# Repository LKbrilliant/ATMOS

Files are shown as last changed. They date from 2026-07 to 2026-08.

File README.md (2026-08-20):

# ATMOS
ATMOS is an embedded, standalone weather forecasting display based on ESP32-S3.

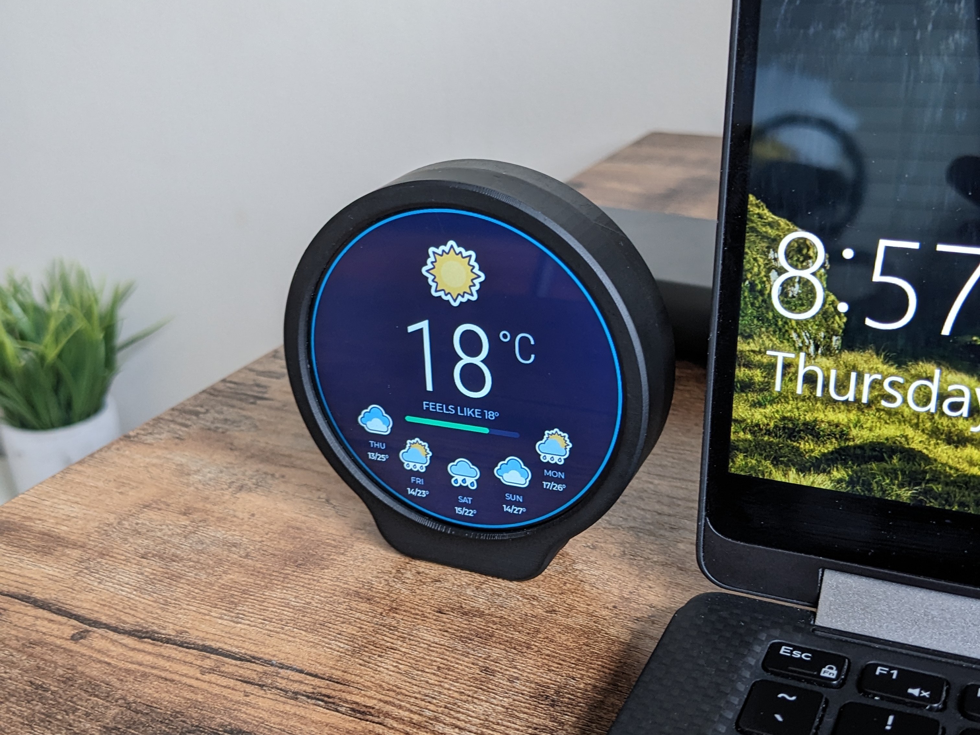
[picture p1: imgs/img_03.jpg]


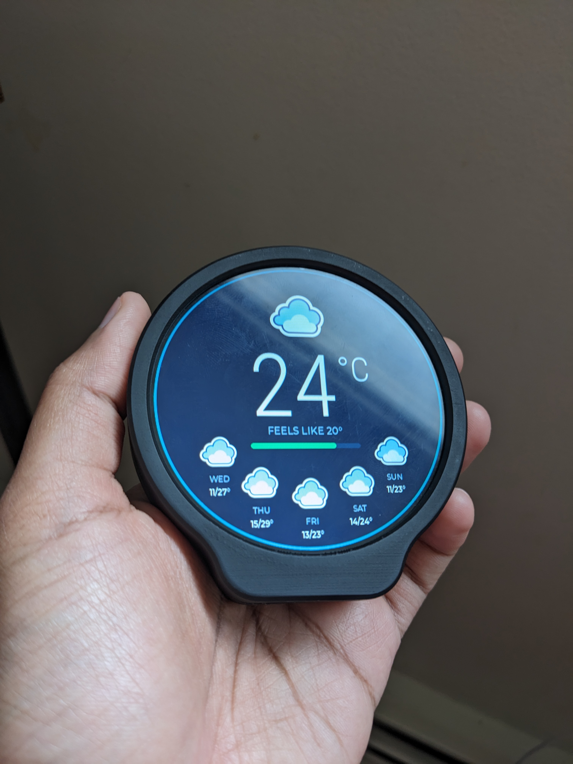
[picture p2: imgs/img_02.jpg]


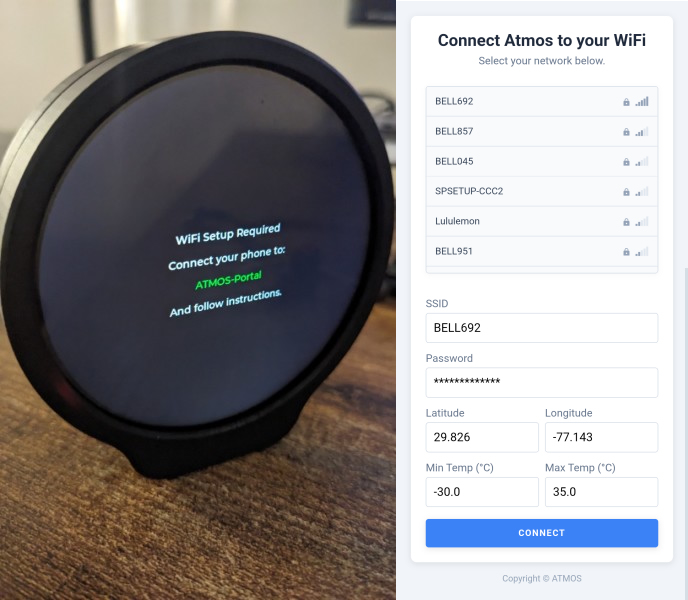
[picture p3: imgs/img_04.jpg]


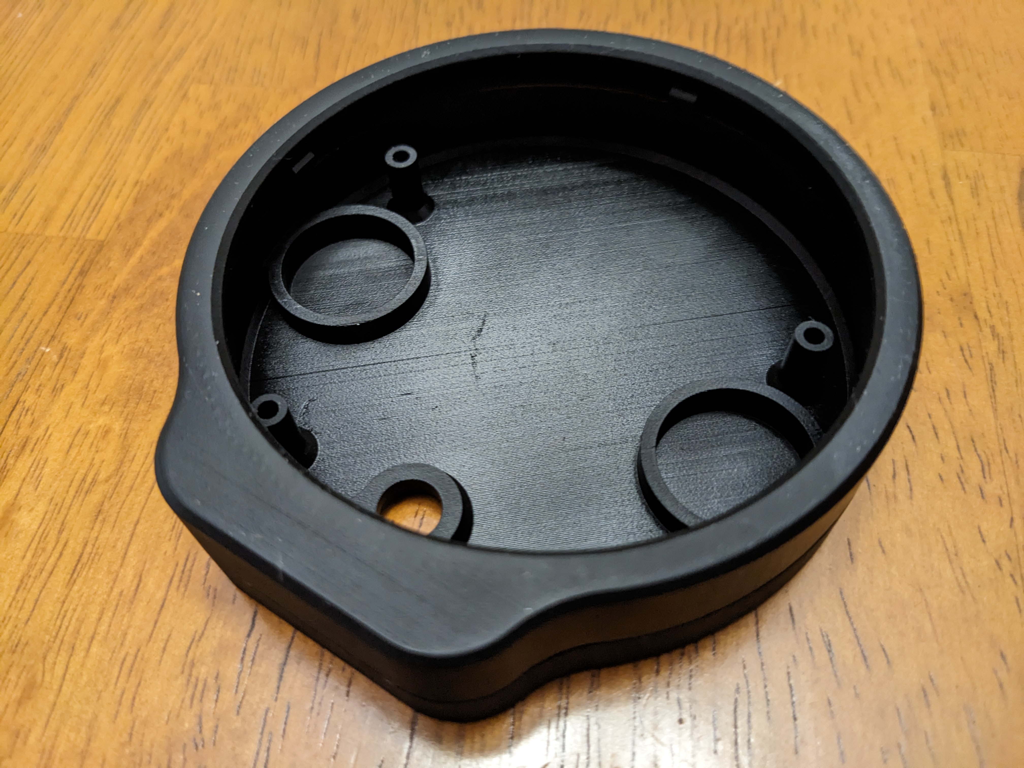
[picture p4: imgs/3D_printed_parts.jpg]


## Features

* **Automatic Captive Portal:** If no saved Wi-Fi network is found on boot, the device automatically broadcasts a setup Access Point and captive portal.
* **One-Time Configuration:** Easily set up Wi-Fi credentials, GPS coordinates, and custom/local yearly min-max temperature thresholds through the browser interface—stored permanently in NVS memory.
* **Hardware Factory Reset:** Press and hold the onboard **BOOT** button for >3 seconds to erase saved network credentials and location data.
* **Weather Data:** Integrates with the [Open-Meteo API](https://open-meteo.com/) to fetch current and forecast metrics (weather, current temperature, "feels like" temperature, and daily min/max temperatures).
* **Comfort Bar:** Generates a color gradient bar based on your custom temperature bounds:
  * **Min Temp** $\rightarrow$ Cold (Purple)
  * **21 °C** $\rightarrow$ Ideal Comfort (Green)
  * **Max Temp** $\rightarrow$ Hot (Red)
* **Tap/raise to wake up:** Gently tap or bump the unit to wake the display and boost brightness back to 100%

## Known issues
- Color inversion and upward shift of the display at the first UI draw (right after setting the credentials). Quick reset or power on/off will resolve the issue. This only occur at the initial setup.

### Hardware
- Display: Waveshare ESP32-S3 2.8" non-touch
- 1GB micro SD card (FAT32) with the weather icons (.bin formatted) in its root directory.
- 3D printed enclosure
- 2000mAh lipo battery
- USB type C female connector
- Latching switch
- 4x M2-15mm mounting screws

### External libraries
- WiFi provisioner: https://github.com/MichMich/esp-idf-wifi-provisioner

### Custom fonts
- Used LVGL online font converter:  https://lvgl.io/tools/fontconverter
    - Bpp:4 bit-per-pixel
    - output format: C file
- Place the C file in the main.c directory
- in the font C file comment out "// .static_bitmap = 0" line. This gave me an error when uncommented.
- Add the font file name to "SRCS" list in CMakeLists.txt

### Weather icons
- Sticker style weather icons: https://icons8.com/icons/set/weather--style-stickers

### Image transform scripts
- src/scripts/resizer.py: Used to batch resize images in a given directory
- src/scripts/img_to_bin_lvgl_v8: Used to convert regular image files in to .bin files to load on display with minimum RAM usage.

# Notes

### Build instructions using ESP-IDF via VScode
- Started from the the manufacturer's (waveshare) demo files which uses LVGL v8
- Install ESP IDF for vs code - IDF version: v5.5.2
- Connect the USB cable to UART or USB port of the device
- Select flash method: UART or USB-JTAG based on the connected port
- Select the USB port using the detect button on VScode (this option is enabled via ESP IDF)
- Select the target: ESP32-S3 (via built in USB-JTAG)
- Do a 'Full clean'
- Then 'Build'

### Changes to the vscode ESP-IDF environment
- Enable fonts
    - lv_font_montserrat_12
    - lv_font_montserrat_16
    - lv_font_montserrat_48
- Enable 'File system on top of posix API' needed for custom file system wrapper
    - Drive letter = '83' for letter S
    - working directory = /sdcard
- FAT Filesystem support -> Long file name support = 'long file name buffer in heap'
    - Note: Maybe this is why I had to implement a custom file wrapper. By default files were not opening may be due to file name length restriction.
    - Note: Could have put the images in the ESP32 instead of the SD card.

### Disclaimer
- Most of the code in this repository was generated with the assistance of AI. While reasonable effort has been made to review and test the generated code, it has not been formally audited. Use this software at your own risk, and verify its correctness and security before deploying it in production.

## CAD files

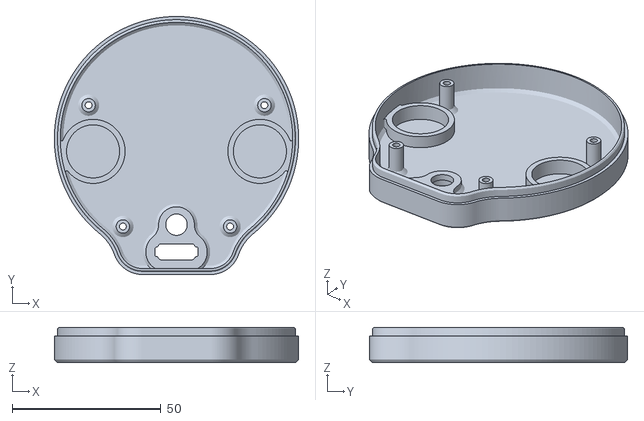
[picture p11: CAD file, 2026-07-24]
CAD/enclosure-case_back.stl
82.0 x 86.6 x 11.8

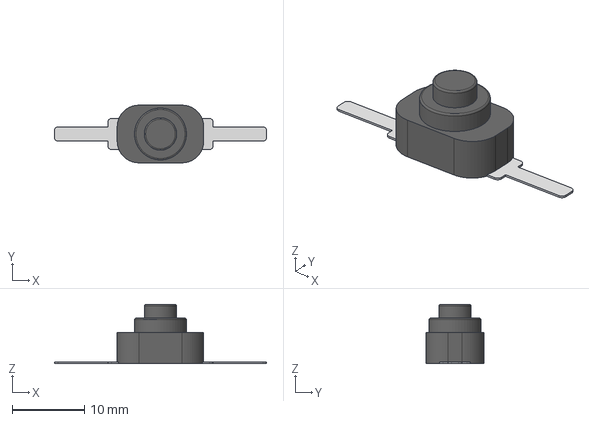
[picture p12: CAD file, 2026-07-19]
CAD/components/Power button.step
29.4 x 8.00 x 8.20 mm

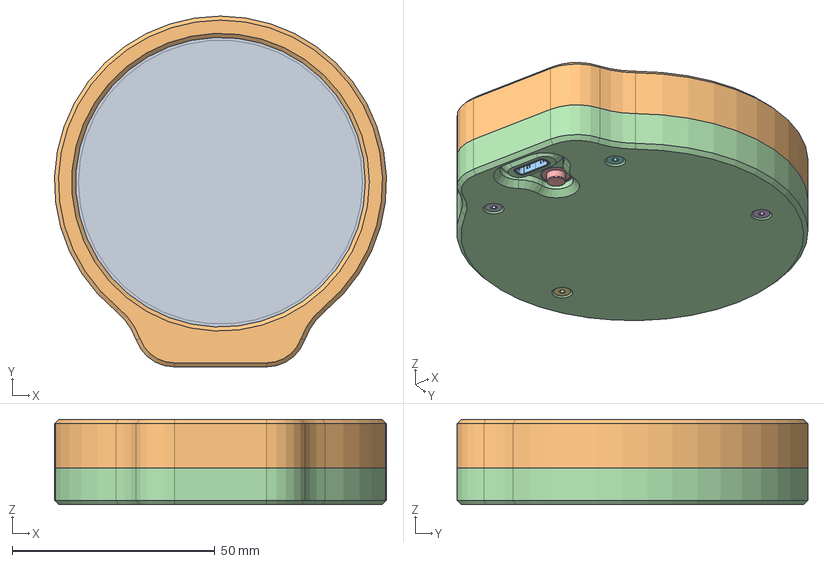
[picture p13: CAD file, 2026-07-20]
CAD/enclosure.FCStd
82.0 x 86.6 x 21.0 mm
Display
case_front
battery_103450
case_back
USB Connector Type C female v1
USB Connector Type C female v001
USB Connector Type C female v002
USB Connector Type C female v003
USB Connector Type C female v004
USB Connector Type C female v005
USB Connector Type C female v006
USB Connector Type C female v007
USB Connector Type C female v008
USB Connector Type C female v009
USB Connector Type C female v010
USB Connector Type C female v011
USB Connector Type C female v012
USB Connector Type C female v013
USB Connector Type C female v014
USB Connector Type C female v015
USB Connector Type C female v016
USB Connector Type C female v017
USB Connector Type C female v018
USB Connector Type C female v019
USB Connector Type C female v020
USB Connector Type C female v021
USB Connector Type C female v022
USB Connector Type C female v023
USB Connector Type C female v024
USB Connector Type C female v025
USB Connector Type C female v026
USB Connector Type C female v027
USB Connector Type C female v028
USB Connector Type C female v029
USB Connector Type C female v030
switch
screw_01
screw_02
screw_03
screw_04

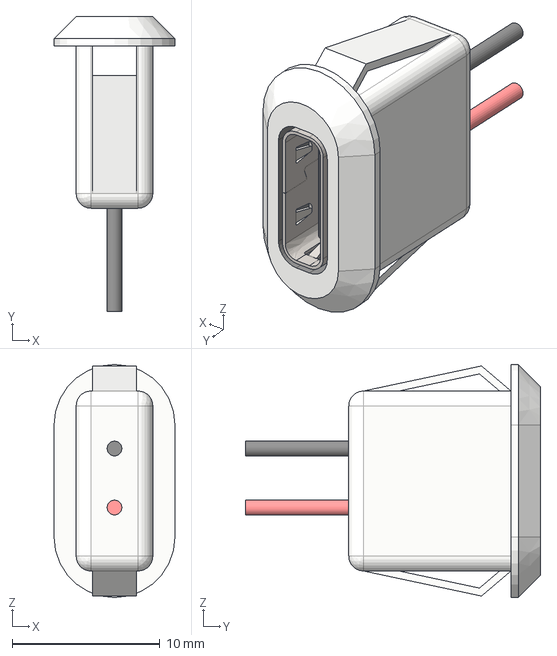
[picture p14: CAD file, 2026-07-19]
CAD/components/type c jack connector.step
8.20 x 20.0 x 15.8 mm
USB Connector Type C female

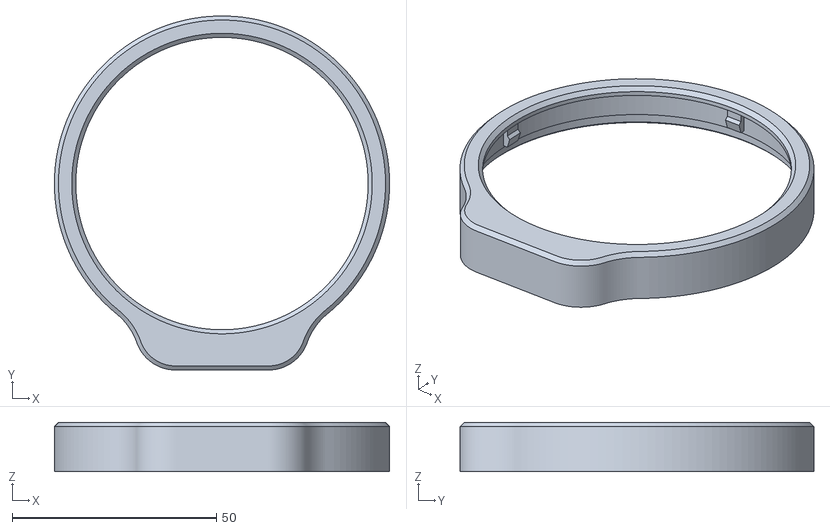
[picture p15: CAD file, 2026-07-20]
CAD/enclosure-case_front.stl
82.0 x 86.6 x 12.0

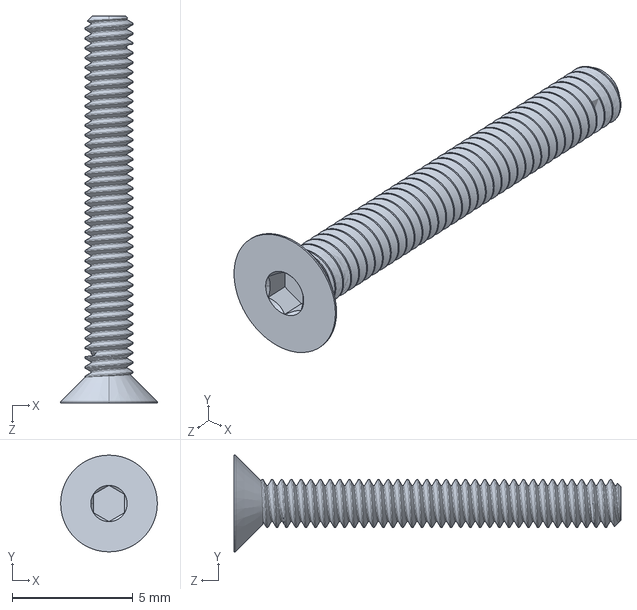
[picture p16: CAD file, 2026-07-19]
CAD/components/92125A059_18-8 Stainless Steel Hex-Drive Flat Head Screw.STEP
4.00 x 4.00 x 16.0 mm

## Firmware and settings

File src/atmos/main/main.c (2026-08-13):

#include <stdio.h>
#include <math.h>
#include <time.h>

#include "sdkconfig.h"
#include "freertos/FreeRTOS.h"
#include "freertos/task.h"
#include "freertos/semphr.h"
#include "driver/ledc.h"
#include "driver/gpio.h"
#include "esp_log.h"
#include "esp_http_client.h"
#include "esp_wifi.h"
#include "esp_sleep.h"
#include "esp_timer.h"
#include "cJSON.h"

#include "QMI8658.h"
#include "ST7701S.h"
#include "TCA9554PWR.h"
#include "SD_MMC.h"
#include "LVGL_Driver.h"
#include "LVGL_Example.h"
#include "BAT_Driver.h"
#include "wifi_provisioner.h"
#include "nvs_flash.h"

/* --- LOG TAG --- */
static const char *TAG = "ATMOS_MAIN";

/* --- FONTS --- */
LV_FONT_DECLARE(roboto_condensed_light_150)
LV_FONT_DECLARE(roboto_condensed_light_60)

/* --- CONFIGURATION & CONSTANTS --- */
#define UPDATE_INTERVAL_MIN    15
#define MAX_HTTP_RECV_BUFFER   4096

#define COLOR_APP_BACKGROUND   0x0F172A // Dark Blue
#define COLOR_OUTER_RING       0x06B6D4 // Cyan / Bright Blue

#define RESET_BUTTON_GPIO      GPIO_NUM_0
#define HOLD_TIME_MS           3000

#define BACKLIGHT_PIN          GPIO_NUM_6
#define BACKLIGHT_SPEED_MODE   LEDC_LOW_SPEED_MODE
#define BACKLIGHT_CHANNEL      LEDC_CHANNEL_0
#define BACKLIGHT_TIMER        LEDC_TIMER_0
#define BACKLIGHT_DUTY_RES     LEDC_TIMER_10_BIT

#define BRIGHTNESS_DIM_TIMEOUT_MS   20000
#define BRIGHTNESS_HIGH             100   // Full brightness percentage
#define BRIGHTNESS_LOW              10    // Dimmed brightness percentage

#define TAP_THRESHOLD_G             0.07f  // Acceleration magnitude change threshold in g (best=0.07f)
#define TAP_DEBOUNCE_MS             300   // Minimum time between tap detections

static esp_timer_handle_t dim_timer = NULL;
static uint32_t last_tap_time_ms = 0;

/* --- FALLBACK VALUES --- */
static float g_temp_low_end = -30.0f;
static float g_temp_high_end = 35.0f;
static char g_latitude[16]   = "49.826";
static char g_longitude[16]  = "-97.143";

static SemaphoreHandle_t lvgl_mux = NULL;
static lv_obj_t *wifi_status_label = NULL;
static lv_obj_t *wifi_screen = NULL;
static lv_fs_drv_t my_sd_drv;

/* --- PERSISTENT LVGL UI HANDLES --- */
static lv_obj_t * main_icon_img   = NULL;
static lv_obj_t * temp_num_label  = NULL;
static lv_obj_t * temp_unit_lbl   = NULL;
static lv_obj_t * feels_like_lbl  = NULL;
static lv_obj_t * range_bar_obj   = NULL;
static lv_obj_t * sub_icons[5]    = {NULL};
static lv_obj_t * day_labels[5]   = {NULL};
static lv_obj_t * min_max_lbls[5] = {NULL};

/* --- DATA STRUCTURES --- */
typedef struct {
    float temp;
    float feels_like;
    int weather_code;
    int is_day;
} current_weather_t;

typedef struct {
    char date[8][16];
    float temp_max[8];
    float temp_min[8];
    int weather_code[8];
    float moon_phase[8];
} forecast_weather_t;

static current_weather_t current_weather;
static forecast_weather_t forecast_weather;

/* --- LVGL MUTEX LOCK HELPER FUNCTIONS --- */
void lvgl_lock(void) 
{
    if (lvgl_mux != NULL) {
        xSemaphoreTake(lvgl_mux, portMAX_DELAY);
    }
}

void lvgl_unlock(void) 
{
    if (lvgl_mux != NULL) {
        xSemaphoreGive(lvgl_mux);
    }
}

/* --- HARDWARE & BACKLIGHT HANDLERS --- */
void init_backlight_pwm(void) 
{
    ledc_timer_config_t ledc_timer = {
        .speed_mode       = BACKLIGHT_SPEED_MODE,
        .timer_num        = BACKLIGHT_TIMER,
        .duty_resolution  = BACKLIGHT_DUTY_RES,
        .freq_hz          = 5000,
        .clk_cfg          = LEDC_AUTO_CLK
    };
    ledc_timer_config(&ledc_timer);

    ledc_channel_config_t ledc_channel = {
        .speed_mode     = BACKLIGHT_SPEED_MODE,
        .channel        = BACKLIGHT_CHANNEL,
        .timer_sel      = BACKLIGHT_TIMER,
        .intr_type      = LEDC_INTR_DISABLE,
        .gpio_num       = BACKLIGHT_PIN,
        .duty           = 1023,
        .hpoint         = 0
    };
    ledc_channel_config(&ledc_channel);
}

void set_backlight_brightness(uint8_t brightness_percent) 
{
    if (brightness_percent > 100) brightness_percent = 100;
    uint32_t duty = (uint32_t)((brightness_percent / 100.0f) * 1023.0f);

    ledc_set_duty(BACKLIGHT_SPEED_MODE, BACKLIGHT_CHANNEL, duty);
    ledc_update_duty(BACKLIGHT_SPEED_MODE, BACKLIGHT_CHANNEL);
}

static void dim_timer_callback(void* arg)
{
    set_backlight_brightness(BRIGHTNESS_LOW);
}

void reset_backlight_dim_timer(void)
{
    if (dim_timer == NULL) {
        const esp_timer_create_args_t timer_args = {
            .callback = &dim_timer_callback,
            .name = "backlight_dim_timer"
        };
        esp_timer_create(&timer_args, &dim_timer);
    } else {
        esp_timer_stop(dim_timer);
    }

    esp_timer_start_once(dim_timer, BRIGHTNESS_DIM_TIMEOUT_MS * 1000ULL);
}

void wakeup_display_and_stat_dim_timer(void)
{
    set_backlight_brightness(BRIGHTNESS_HIGH);
    reset_backlight_dim_timer();
}

void check_tap_event(void)
{
    // Calculate total acceleration magnitude vector: sqrt(x^2 + y^2 + z^2)
    float magnitude = sqrtf((Accel.x * Accel.x) + (Accel.y * Accel.y) + (Accel.z * Accel.z));

    // Under normal gravity at rest, magnitude ~1.0g.
    float delta_g = fabsf(magnitude - 1.0f);

    uint32_t current_time_ms = (uint32_t)(esp_timer_get_time() / 1000ULL);

    if (delta_g > TAP_THRESHOLD_G && (current_time_ms - last_tap_time_ms) > TAP_DEBOUNCE_MS) {
        last_tap_time_ms = current_time_ms;
        
        wakeup_display_and_stat_dim_timer();
    }
}

void reset_wifi_and_restart(void)
{
    ESP_LOGW("RESET", "Erasing Wi-Fi credentials via wifi_provisioner...");
    esp_err_t err = wifi_prov_erase_credentials();
    if (err == ESP_OK) {
        ESP_LOGI("RESET", "Wi-Fi credentials erased successfully.");
    } else {
        ESP_LOGE("RESET", "Failed to erase credentials: %s", esp_err_to_name(err));
    }

    vTaskDelay(pdMS_TO_TICKS(500));
    esp_sleep_enable_timer_wakeup(100 * 1000);
    esp_deep_sleep_start();
}

static void reset_button_task(void *pvParameters)
{
    gpio_config_t io_conf = {
        .pin_bit_mask = (1ULL << RESET_BUTTON_GPIO),
        .mode = GPIO_MODE_INPUT,
        .pull_up_en = GPIO_PULLUP_ENABLE,
        .pull_down_en = GPIO_PULLDOWN_DISABLE,
        .intr_type = GPIO_INTR_DISABLE,
    };
    gpio_config(&io_conf);

    uint32_t press_duration = 0;

    while (1) {
        if (gpio_get_level(RESET_BUTTON_GPIO) == 0) {
            press_duration += 100;
            if (press_duration >= HOLD_TIME_MS) {
                ESP_LOGI("RESET", "Reset button hold detected!");
                reset_wifi_and_restart();
            }
        } else {
            press_duration = 0;
        }
        vTaskDelay(pdMS_TO_TICKS(100));
    }
}

void reset_button_init(void)
{
    xTaskCreate(reset_button_task, "reset_button_task", 4096, NULL, 10, NULL);
}

/* --- LVGL CUSTOM SD CARD VFS CALLBACKS --- */
static void * fs_open_cb(struct _lv_fs_drv_t * drv, const char * path, lv_fs_mode_t mode) 
{
    const char * flags = "";
    if(mode == LV_FS_MODE_WR) flags = "wb";
    else if(mode == LV_FS_MODE_RD) flags = "rb";
    else if(mode == (LV_FS_MODE_WR | LV_FS_MODE_RD)) flags = "r+b";

    char full_path[128];
    if (path[0] == '/') {
        snprintf(full_path, sizeof(full_path), "/sdcard%s", path);
    } else {
        snprintf(full_path, sizeof(full_path), "/sdcard/%s", path);
    }

    FILE *f = fopen(full_path, flags);
    if (f == NULL) {
        printf("[LVGL FS ERROR] Failed to open: %s\n", full_path);
    }
    return (void *)f;
}

static lv_fs_res_t fs_close_cb(struct _lv_fs_drv_t * drv, void * file_p) 
{
    if(!file_p) return LV_FS_RES_INV_PARAM;
    fclose((FILE *)file_p);
    return LV_FS_RES_OK;
}

static lv_fs_res_t fs_read_cb(struct _lv_fs_drv_t * drv, void * file_p, void * buf, uint32_t btr, uint32_t * br) 
{
    if(!file_p || !buf) return LV_FS_RES_INV_PARAM;
    *br = fread(buf, 1, btr, (FILE *)file_p);
    return LV_FS_RES_OK;
}

static lv_fs_res_t fs_seek_cb(struct _lv_fs_drv_t * drv, void * file_p, uint32_t pos, lv_fs_whence_t whence) 
{
    if(!file_p) return LV_FS_RES_INV_PARAM;
    int w = SEEK_SET;
    if(whence == LV_FS_SEEK_CUR) w = SEEK_CUR;
    else if(whence == LV_FS_SEEK_END) w = SEEK_END;
    
    fseek((FILE *)file_p, pos, w);
    return LV_FS_RES_OK;
}

static lv_fs_res_t fs_tell_cb(struct _lv_fs_drv_t * drv, void * file_p, uint32_t * pos_p) 
{
    if(!file_p || !pos_p) return LV_FS_RES_INV_PARAM;
    *pos_p = ftell((FILE *)file_p);
    return LV_FS_RES_OK;
}

void register_custom_sd_driver(void) 
{
    lv_fs_drv_init(&my_sd_drv);
    my_sd_drv.letter = 'S';
    my_sd_drv.open_cb = fs_open_cb;
    my_sd_drv.close_cb = fs_close_cb;
    my_sd_drv.read_cb = fs_read_cb;
    my_sd_drv.seek_cb = fs_seek_cb;
    my_sd_drv.tell_cb = fs_tell_cb;
    lv_fs_drv_register(&my_sd_drv);
    ESP_LOGI(TAG, "LVGL Driver S: mapped to /sdcard/");
}

/* --- CALCULATIONS & UTILITIES --- */
static float calculate_local_moon_phase(const char* date_str) 
{
    int year, month, day;
    if (sscanf(date_str, "%d-%d-%d", &year, &month, &day) != 3) {
        return 0.25f;
    }

    struct tm t = {0};
    t.tm_year = year - 1900;
    t.tm_mon = month - 1;
    t.tm_mday = day;
    time_t target_time = mktime(&t);

    const time_t known_new_moon = 947116800; // Jan 6, 2000
    const double synodic_month = 2551443;   // 29.53059 days

    if (target_time < known_new_moon) return 0.0f;

    double diff_seconds = difftime(target_time, known_new_moon);
    double cycle_position = fmod(diff_seconds, synodic_month);
    return (float)(cycle_position / synodic_month);
}

const char* get_weekday_from_date(const char* date_str) 
{
    int y, m, d;
    if (sscanf(date_str, "%d-%d-%d", &y, &m, &d) != 3) return "???";

    if (m < 3) {
        m += 12;
        y--;
    }
    int k = y % 100;
    int j = y / 100;
    int h = (d + 13 * (m + 1) / 5 + k + k / 4 + j / 4 + 5 * j) % 7;

    const char* days[] = {"SAT", "SUN", "MON", "TUE", "WED", "THU", "FRI"};
    return days[h];
}

static lv_color_t get_temp_color(float temp) 
{
    if (temp < g_temp_low_end)  temp = g_temp_low_end;
    if (temp > g_temp_high_end) temp = g_temp_high_end;

    float temp_green_target = 21.0f;
    float temp_blue_mid = g_temp_low_end + (temp_green_target - g_temp_low_end) / 2.0f;

    lv_color_t purple_cold = lv_color_hex(0xA855F7);
    lv_color_t blue_mid    = lv_color_hex(0x3498DB);
    lv_color_t green_nice  = lv_color_hex(0x2ECC71);
    lv_color_t red_hot     = lv_color_hex(0xEF4444);

    if (temp < temp_blue_mid) {
        float range_span = temp_blue_mid - g_temp_low_end;
        uint8_t ratio = (uint8_t)(((temp - g_temp_low_end) / range_span) * 255.0f);
        return lv_color_mix(blue_mid, purple_cold, ratio);
    } else if (temp < temp_green_target) {
        float range_span = temp_green_target - temp_blue_mid;
        uint8_t ratio = (uint8_t)(((temp - temp_blue_mid) / range_span) * 255.0f);
        return lv_color_mix(green_nice, blue_mid, ratio);
    } else {
        float range_span = g_temp_high_end - temp_green_target;
        uint8_t ratio = (uint8_t)(((temp - temp_green_target) / range_span) * 255.0f);
        return lv_color_mix(red_hot, green_nice, ratio);
    }
}

static void get_main_icon_path(char *buffer, size_t max_len) 
{
    int code = current_weather.weather_code;

    if (current_weather.is_day == 0) {
        if (code == 0) {
            float moon = calculate_local_moon_phase(forecast_weather.date[0]);
            if (moon < 0.05f || moon > 0.95f) {
                snprintf(buffer, max_len, "S:/0_new_moon_100.bin");
                return;
            } else if (moon > 0.45f && moon < 0.55f) {
                snprintf(buffer, max_len, "S:/0_full_moon_100.bin");
                return;
            } else {
                snprintf(buffer, max_len, "S:/0_night_100.bin");
                return;
            }
        }
        
        if (code == 1 || code == 45 || code == 48 || code == 51 || code == 53 || code == 55) {
            snprintf(buffer, max_len, "S:/%d_night_100.bin", code);
            return;
        }
    }

    snprintf(buffer, max_len, "S:/%d_100.bin", code);
}

void build_weather_ui_once(void) 
{
    lv_obj_set_style_bg_color(lv_scr_act(), lv_color_hex(COLOR_APP_BACKGROUND), 0);
    lv_obj_clear_flag(lv_scr_act(), LV_OBJ_FLAG_SCROLLABLE);

    // --- MAIN ICON ---
    main_icon_img = lv_img_create(lv_scr_act());
    lv_obj_align(main_icon_img, LV_ALIGN_TOP_MID, 0, 40); 

    // --- CURRENT TEMP ---
    temp_num_label = lv_label_create(lv_scr_act());
    lv_obj_set_style_text_font(temp_num_label, &roboto_condensed_light_150, 0); 
    lv_obj_set_style_text_color(temp_num_label, lv_color_white(), 0);
    lv_obj_align(temp_num_label, LV_ALIGN_TOP_MID, -15, 160); 

    temp_unit_lbl = lv_label_create(lv_scr_act());
    lv_obj_set_style_text_font(temp_unit_lbl, &roboto_condensed_light_60, 0);
    lv_obj_set_style_text_color(temp_unit_lbl, lv_color_hex(0xCBD5E1), 0);
    lv_label_set_text(temp_unit_lbl, "°C");
    lv_obj_align_to(temp_unit_lbl, temp_num_label, LV_ALIGN_OUT_RIGHT_TOP, 2, 4);

    // --- FEELS LIKE ---
    feels_like_lbl = lv_label_create(lv_scr_act());
    lv_obj_set_style_text_font(feels_like_lbl, &lv_font_montserrat_16, 0);
    lv_obj_set_style_text_color(feels_like_lbl, lv_color_hex(0x94A3B8), 0);
    lv_obj_align(feels_like_lbl, LV_ALIGN_TOP_MID, 0, 285);

    // --- RANGE BAR ---
    range_bar_obj = lv_bar_create(lv_scr_act());
    lv_obj_set_size(range_bar_obj, 180, 8);
    lv_obj_align(range_bar_obj, LV_ALIGN_TOP_MID, 0, 315);
    lv_obj_set_style_bg_opa(range_bar_obj, LV_OPA_COVER, LV_PART_INDICATOR); 
    lv_obj_set_style_radius(range_bar_obj, 4, 0);

    // --- 5-DAY FORECAST RADIAL DISPLAY ---
    int items_count = 5;
    float start_angle_deg = 140.0f;
    float end_angle_deg   = 40.0f;
    float angle_step = (end_angle_deg - start_angle_deg) / (items_count - 1);
    float radius = 185.0f; 

    for (int i = 0; i < items_count; i++) {
        float current_angle_deg = start_angle_deg + (i * angle_step);
        float angle_rad = current_angle_deg * (M_PI / 180.0f);

        int x_pos = (int)(radius * cosf(angle_rad));
        int y_pos = (int)(radius * sinf(angle_rad));

        lv_obj_t * col = lv_obj_create(lv_scr_act());
        lv_obj_set_size(col, 75, 120);
        lv_obj_clear_flag(col, LV_OBJ_FLAG_SCROLLABLE);
        lv_obj_set_style_bg_opa(col, LV_OPA_TRANSP, 0);
        lv_obj_set_style_border_width(col, 0, 0);
        lv_obj_set_style_pad_all(col, 0, 0);
        lv_obj_align(col, LV_ALIGN_CENTER, x_pos, y_pos);

        sub_icons[i] = lv_img_create(col);
        lv_obj_align(sub_icons[i], LV_ALIGN_TOP_MID, 0, 0);

        day_labels[i] = lv_label_create(col);
        lv_obj_set_style_text_font(day_labels[i], &lv_font_montserrat_12, 0);
        lv_obj_set_style_text_color(day_labels[i], lv_color_hex(0x94A3B8), LV_PART_MAIN);
        lv_obj_align(day_labels[i], LV_ALIGN_TOP_MID, 0, 65);

        min_max_lbls[i] = lv_label_create(col);
        lv_obj_set_style_text_font(min_max_lbls[i], &lv_font_montserrat_12, 0);
        lv_obj_set_style_text_color(min_max_lbls[i], lv_color_white(), 0);
        lv_obj_align(min_max_lbls[i], LV_ALIGN_TOP_MID, 0, 85);
    }

    // --- OUTER BEZEL RING ---
    lv_obj_t * edge_ring = lv_obj_create(lv_scr_act());
    lv_obj_set_size(edge_ring, 480, 480);
    lv_obj_center(edge_ring);
    lv_obj_clear_flag(edge_ring, LV_OBJ_FLAG_SCROLLABLE);
    lv_obj_add_flag(edge_ring, LV_OBJ_FLAG_IGNORE_LAYOUT);
    lv_obj_set_style_bg_opa(edge_ring, LV_OPA_TRANSP, 0);
    lv_obj_set_style_pad_all(edge_ring, 0, 0);
    lv_obj_set_style_radius(edge_ring, LV_RADIUS_CIRCLE, 0);
    lv_obj_set_style_border_color(edge_ring, lv_color_hex(COLOR_OUTER_RING), 0); 
    lv_obj_set_style_border_width(edge_ring, 4, 0);
    lv_obj_set_style_border_opa(edge_ring, LV_OPA_80, 0);
}

void update_weather_ui_data(void)
{
    // 1. Update Main Weather Icon
    char main_icon_path[64];
    get_main_icon_path(main_icon_path, sizeof(main_icon_path));
    lv_img_set_src(main_icon_img, main_icon_path);

    // 2. Update Temperature & Feels Like Labels
    lv_label_set_text_fmt(temp_num_label, "%d", (int)current_weather.temp);

    lv_obj_align_to(temp_unit_lbl, temp_num_label, LV_ALIGN_OUT_RIGHT_TOP, 4, 4);

    lv_label_set_text_fmt(feels_like_lbl, "FEELS LIKE %d°", (int)current_weather.feels_like);

    // 3. Update Bar Range & Colors
    lv_bar_set_range(range_bar_obj, (int32_t)g_temp_low_end, (int32_t)g_temp_high_end);
    int32_t bar_val = (int32_t)current_weather.feels_like;
    if (bar_val < (int32_t)g_temp_low_end)  bar_val = (int32_t)g_temp_low_end;
    if (bar_val > (int32_t)g_temp_high_end) bar_val = (int32_t)g_temp_high_end;
    if (bar_val == (int32_t)g_temp_low_end) bar_val = (int32_t)g_temp_low_end + 4; 

    lv_bar_set_value(range_bar_obj, bar_val, LV_ANIM_OFF);
    lv_color_t active_color = get_temp_color(current_weather.feels_like);
    lv_obj_set_style_bg_color(range_bar_obj, lv_color_hex(0x758DAD), LV_PART_MAIN); 
    lv_obj_set_style_bg_color(range_bar_obj, active_color, LV_PART_INDICATOR);

    // 4. Update 5-Day Forecast
    for (int i = 0; i < 5; i++) {
        char sub_icon_path[32];
        snprintf(sub_icon_path, sizeof(sub_icon_path), "S:/%d_60.bin", forecast_weather.weather_code[i]);
        
        lv_img_set_src(sub_icons[i], sub_icon_path);
        lv_label_set_text(day_labels[i], get_weekday_from_date(forecast_weather.date[i]));
        lv_label_set_text_fmt(min_max_lbls[i], "%d/%d°", (int)forecast_weather.temp_min[i], (int)forecast_weather.temp_max[i]);
    }
}
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
void app_main(void)
{   
    // Initialize Non-Volatile Storage (NVS)
    esp_err_t ret = nvs_flash_init();
    if (ret == ESP_ERR_NVS_NO_FREE_PAGES || ret == ESP_ERR_NVS_NEW_VERSION_FOUND) {
        ESP_ERROR_CHECK(nvs_flash_erase());
        ret = nvs_flash_init();
    }
    ESP_ERROR_CHECK(ret);

    lvgl_mux = xSemaphoreCreateMutex();
    if (lvgl_mux == NULL) {
        ESP_LOGE(TAG, "Failed to create LVGL Mutex Lock!");
        return;
    }

    // Load active application configuration
    load_system_config();

    // Print active configuration values to console
    ESP_LOGI(TAG, "==================================================");
    ESP_LOGI(TAG, " ACTIVE SYSTEM CONFIGURATION:");
    ESP_LOGI(TAG, "   Latitude:    %s", g_latitude);
    ESP_LOGI(TAG, "   Longitude:   %s", g_longitude);
    ESP_LOGI(TAG, "   Temp Range:  %.1f deg C to %.1f deg C", g_temp_low_end, g_temp_high_end);
    ESP_LOGI(TAG, "==================================================");

    // Hardware & display drivers initialization
    Driver_Init();
    LCD_Init();
    SD_Init();
    LVGL_Init();
    register_custom_sd_driver();
    init_backlight_pwm();
    wakeup_display_and_stat_dim_timer();

    // Wi-Fi & Captive Portal setup
    wifi_prov_config_t config = WIFI_PROV_DEFAULT_CONFIG();
    config.ap_ssid              = "ATMOS-Portal";
    config.page_title           = "ATMOS Network Setup";
    config.portal_header        = "Connect Atmos to your WiFi";
    config.portal_subheader     = "Select your network below.";
    config.connected_header     = "Done!";
    config.connected_subheader  = "ATMOS is now connected.";
    config.page_footer          = "Copyright &copy; ATMOS";

    config.on_connected   = on_WiFi_connected;
    config.on_portal_start = on_captive_portal_start;

    ESP_ERROR_CHECK(wifi_prov_start(&config));
    
    while (!wifi_prov_is_connected()) {
        lv_timer_handler();
        vTaskDelay(pdMS_TO_TICKS(10));
    }

    if (wifi_screen != NULL) {
        lv_obj_del(wifi_screen);
        wifi_screen = NULL;
        wifi_status_label = NULL;
    }

    // Construct Persistent UI Layout ONCE
    lvgl_lock();
    build_weather_ui_once();
    lvgl_unlock();

    xTaskCreatePinnedToCore(
        weather_fetch_task, 
        "Weather Fetch Task", 
        6144, 
        NULL, 
        5, 
        NULL, 
        1);

    reset_button_init();

    // Main LVGL Execution Loop
    while (1) {
        vTaskDelay(pdMS_TO_TICKS(10));
        lvgl_lock();
        lv_timer_handler();
        lvgl_unlock();
    }
}

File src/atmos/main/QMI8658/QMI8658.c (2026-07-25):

#include "QMI8658.h"

IMUdata Accel;
IMUdata Gyro;

uint8_t Device_addr ; // default for SD0/SA0 low, 0x6A if high
acc_scale_t acc_scale = ACC_RANGE_4G;
gyro_scale_t gyro_scale = GYR_RANGE_64DPS;
acc_odr_t acc_odr = acc_odr_norm_8000;
gyro_odr_t gyro_odr = gyro_odr_norm_8000;
sensor_state_t sensor_state = sensor_default;
lpf_t acc_lpf;

// float accelScales, gyroScales;
// float accelScales = 0;

float accelScales = 4.0f / 32768.0f; // Default for ACC_RANGE_4G
float gyroScales = 64.0f / 32768.0f;

uint8_t readings[12];
uint32_t reading_timestamp_us; // timestamp in arduino micros() time
/**
 * Inialize Wire and send default configs
 * @param addr I2C address of sensor, typically 0x6A or 0x6B
 */
void QMI8658_Init(void)
{
    uint8_t buf[1];
    Device_addr = QMI8658_L_SLAVE_ADDRESS;     
    I2C_Read(Device_addr, QMI8658_REVISION_ID, buf, 1);
    printf("QMI8658 Device ID: %x\r\n",buf[0]);    // Get chip id
    setState(sensor_running);             

    setAccScale(acc_scale);            
    setAccODR(acc_odr);                    
    setAccLPF(LPF_MODE_0);                  
    switch (acc_scale) {                
        // Possible accelerometer scales (and their register bit settings) are:
        // 2 Gs (00), 4 Gs (01), 8 Gs (10), and 16 Gs  (11).
        // Here's a bit of an algorith to calculate DPS/(ADC tick) based on that
        // 2-bit value:
        case ACC_RANGE_2G:  accelScales = 2.0 / 32768.0; break;
        case ACC_RANGE_4G:  accelScales = 4.0 / 32768.0; break;
        case ACC_RANGE_8G:  accelScales = 8.0 / 32768.0; break;
        case ACC_RANGE_16G: accelScales = 16.0 / 32768.0; break;
    }

    setGyroScale(gyro_scale);              
    setGyroODR(gyro_odr);                       
    setGyroLPF(LPF_MODE_3);                
    switch (gyro_scale) {                  
        // Possible gyro scales (and their register bit settings) are:
        // 250 DPS (00), 500 DPS (01), 1000 DPS (10), and 2000 DPS  (11).
        // Here's a bit of an algorith to calculate DPS/(ADC tick) based on that
        // 2-bit value:
        case GYR_RANGE_16DPS: gyroScales = 16.0 / 32768.0; break;
        case GYR_RANGE_32DPS: gyroScales = 32.0 / 32768.0; break;
        case GYR_RANGE_64DPS: gyroScales = 64.0 / 32768.0; break;
        case GYR_RANGE_128DPS: gyroScales = 128.0 / 32768.0; break;
        case GYR_RANGE_256DPS: gyroScales = 256.0 / 32768.0; break;
        case GYR_RANGE_512DPS: gyroScales = 512.0 / 32768.0; break;
        case GYR_RANGE_1024DPS: gyroScales = 1024.0 / 32768.0; break;
    }
}
void QMI8658_Loop(void)
{
  getAccelerometer();
  check_tap_event();  // Check if current reading indicates a tap
}

/**
 * Transmit one uint8_t of data to QMI8658.
 * @param addr address of data to be written
 * @param data the data to be written
 */
void QMI8658_transmit(uint8_t addr, uint8_t data)
{
    I2C_Write(Device_addr, addr, &data, 1);
}

/**
 * Receive one uint8_t of data from QMI8658.
 * @param addr address of data to be read
 * @return the uint8_t of data that was read
 */
uint8_t QMI8658_receive(uint8_t addr)
{
    uint8_t retval;
    I2C_Read(Device_addr, addr, &retval, 1);
    return retval;
}

/**
 * Writes data to CTRL9 (command register) and waits for ACK.
 * @param command the command to be executed
 */
void QMI8658_CTRL9_Write(uint8_t command)
{
    // transmit command
    QMI8658_transmit(QMI8658_CTRL9, command);

    // wait for command to be done
    while (((QMI8658_receive(QMI8658_STATUSINT)) & 0x80) == 0x00);
}

/**
 * Set output data rate (ODR) of accelerometer.
 * @param odr acc_odr_t variable representing new data rate
 */
void setAccODR(acc_odr_t odr)
{
    if (sensor_state != sensor_default)                     // If the device is not in the default state
    {
        uint8_t ctrl2 = QMI8658_receive(QMI8658_CTRL2);
        ctrl2 &= ~QMI8658_AODR_MASK;                        // clear previous setting
        ctrl2 |= odr;                                       // OR in new setting
        QMI8658_transmit(QMI8658_CTRL2, ctrl2);
    }
    acc_odr = odr;
}

/**
 * Set output data rate (ODR) of gyro.
 * @param odr gyro_odr_t variable representing new data rate
 */
void setGyroODR(gyro_odr_t odr)
{
    if (sensor_state != sensor_default)
    {
    uint8_t ctrl3 = QMI8658_receive(QMI8658_CTRL3);
    ctrl3 &= ~QMI8658_GODR_MASK; // clear previous setting
    ctrl3 |= odr; // OR in new setting
    QMI8658_transmit(QMI8658_CTRL3, ctrl3);
    }
    gyro_odr = odr;
}

/**
 * Set scale of accelerometer output.
 * @param scale acc_scale_t variable representing new scale
 */
void setAccScale(acc_scale_t scale)
{
    if (sensor_state != sensor_default)
    {
    uint8_t ctrl2 = QMI8658_receive(QMI8658_CTRL2);
    ctrl2 &= ~QMI8658_ASCALE_MASK; // clear previous setting
    ctrl2 |= scale << QMI8658_ASCALE_OFFSET; // OR in new setting
    QMI8658_transmit(QMI8658_CTRL2, ctrl2);
    }
    acc_scale = scale;
}

/**
 * Set scale of gyro output.
 * @param scale gyro_scale_t variable representing new scale
 */
void setGyroScale(gyro_scale_t scale)
{
    if (sensor_state != sensor_default)
    {
    uint8_t ctrl3 = QMI8658_receive(QMI8658_CTRL3);
    ctrl3 &= ~QMI8658_GSCALE_MASK; // clear previous setting
    ctrl3 |= scale << QMI8658_GSCALE_OFFSET; // OR in new setting
    QMI8658_transmit(QMI8658_CTRL3, ctrl3);
    }
    gyro_scale = scale;
}

/**
 * Set new low-pass filter value for accelerometer
 * @param lp lpf_t variable representing new low-pass filter value
 */
void setAccLPF(lpf_t lpf)
{
    if (sensor_state != sensor_default)
    {
    uint8_t ctrl5 = QMI8658_receive(QMI8658_CTRL5);
    ctrl5 &= !QMI8658_ALPF_MASK;
    ctrl5 |= lpf << QMI8658_ALPF_OFFSET;
    ctrl5 |= 0x01; // turn on acc low pass filter
    QMI8658_transmit(QMI8658_CTRL5, ctrl5);
    }
    acc_lpf = lpf;
}

/**
 * Set new low-pass filter value for gyro
 * @param lp lpf_t variable representing new low-pass filter value
 */
void setGyroLPF(lpf_t lpf)
{
    if (sensor_state != sensor_default)
    {
    uint8_t ctrl5 = QMI8658_receive(QMI8658_CTRL5);
    ctrl5 &= !QMI8658_GLPF_MASK;
    ctrl5 |= lpf << QMI8658_GLPF_OFFSET;
    ctrl5 |= 0x10; // turn on gyro low pass filter
    QMI8658_transmit(QMI8658_CTRL5, ctrl5);
    }
}
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

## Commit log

2026-07-20 Enclosure without logo
    [enclosure-case_back.stl, enclosure-case_front.stl, enclosure.FCStd]
2026-07-24 Reset WiFi credentials by pressing and holding the boot button.
    [main.c]
2026-07-24 Fixed missing wall, removed logo, add magnet holders
    [enclosure-case_back.stl]
2026-07-24 fixed display artifacts during credential resetting.
    [main.c]
2026-07-26 Backlight init earlier to prevent cold boot blackouts
    [main.c]
